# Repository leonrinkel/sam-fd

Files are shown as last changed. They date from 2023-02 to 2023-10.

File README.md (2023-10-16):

# sam-fd

ATSAMC21 based CAN-FD interface

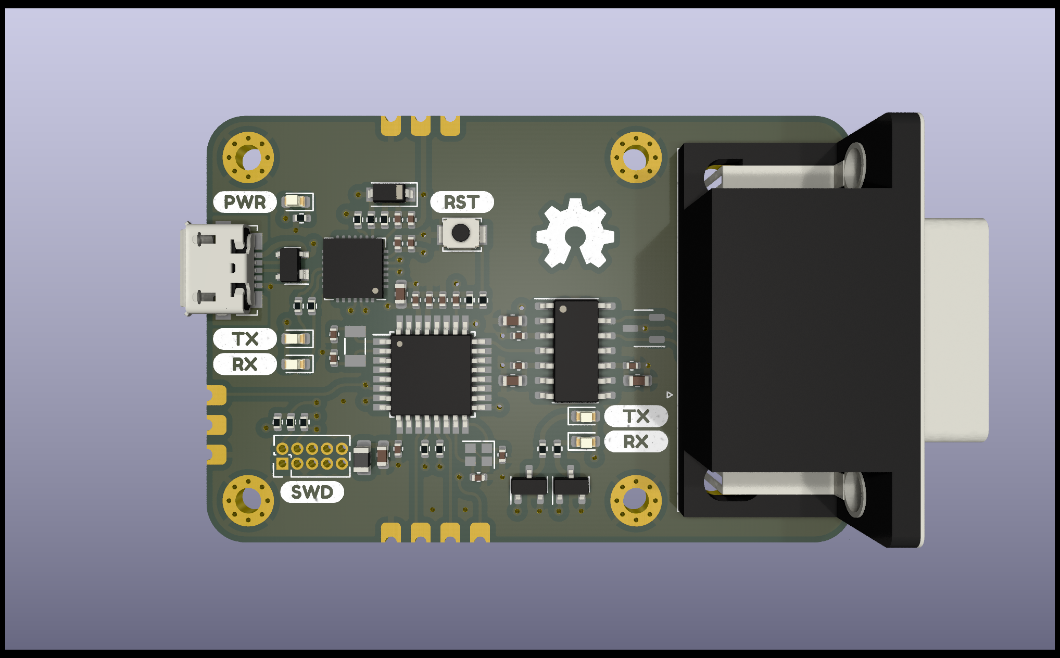
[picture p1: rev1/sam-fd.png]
Render of the interface PCB


## Initialization

Make sure you have a proper Zephyr development environment according to the official documentation.

```sh
west init -m https://git.leon.fyi/sam-fd-sdk --mr main sam-fd-workspace # or
west init -m https://github.com/leonrinkel/sam-fd-sdk --mr main sam-fd-workspace
cd sam-fd-workspace
west update
```

## Building

```sh
west build --sysbuild -b sam_fd sam-fd-sdk/app
```

## Flashing

### Using a Debugger

```sh
west flash --runner jlink # or
west flash --runner pyocd
```

### Via Serial Recovery

Serial recovery mode can be entered by running a command like the following immediately after resetting.

```sh
mcumgr \
    --conntype serial \
    --connstring dev=/dev/cu.usbserial-110,baud=115200 \
    image upload -e build/app/zephyr/zephyr.signed.bin
```

## License

Please see [hardware/LICENSE](rev1/LICENSE) and [sam-fd-sdk](https://git.leon.fyi/sam-fd-sdk). The software side of this project is based on [Zephyr](https://www.zephyrproject.org) which is mostly licensed under the [Apache-2.0](http://www.apache.org/licenses/LICENSE-2.0) license.

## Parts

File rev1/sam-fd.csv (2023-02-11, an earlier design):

Source: | /Users/leonrinkel/Documents/Git/leonrinkel/sam-fd/hardware/sam-fd.kicad_sch
Date: | 2023 February 11, Saturday 17:33:37
Tool: | Eeschema (6.0.10-0)
Generator: | /Applications/KiCad/KiCad.app/Contents/SharedSupport/plugins/bom_csv_grouped_by_value.py
Component Count: | 63
Individual Components:
Item | Qty | Reference(s) | Value | LibPart | Footprint | Datasheet | Mfr. | Mfr. No | Mouser No
 |  | C1 | 100pF | Device:C | Capacitor_SMD:C_0402_1005Metric | ./datasheets/GRM1555C1H101JA01_01A-1982687.pdf | Murata Electronics | GRM1555C1H101JA01D | 81-GRM1555C1H101JA1D
 |  | C2 | 4.7pF | Device:C | Capacitor_SMD:C_0402_1005Metric | ./datasheets/GJM1555C1H4R7WB01_01-1973175.pdf | Murata Electronics | GJM1555C1H4R7WB01D | 81-GJM1555C1H4R7WB1D
 |  | C3 | 4.7pF | Device:C | Capacitor_SMD:C_0402_1005Metric | ./datasheets/GJM1555C1H4R7WB01_01-1973175.pdf | Murata Electronics | GJM1555C1H4R7WB01D | 81-GJM1555C1H4R7WB1D
 |  | C4 | 10µF | Device:C | Capacitor_SMD:C_0603_1608Metric | ./datasheets/GRM188Z71A106KA73_01A-1986029.pdf | Murata Electronics | GRM188Z71A106KA73D | 81-GRM188Z71A106KA3D
 |  | C5 | 100nF | Device:C | Capacitor_SMD:C_0402_1005Metric | ./datasheets/GRM155R71A104KA01_01A-1983947.pdf | Murata Electronics | GRM155R71A104KA01D | 81-GRM155R71A104KA1D
 |  | C6 | 1µF | Device:C | Capacitor_SMD:C_0402_1005Metric | ./datasheets/GCM155C71A105KE38_01-1965360.pdf | Murata Electronics | GCM155C71A105KE38D | 81-GCM155C71A105KE8D
 |  | C7 | 10µF | Device:C | Capacitor_SMD:C_0603_1608Metric | ./datasheets/GRM188Z71A106KA73_01A-1986029.pdf | Murata Electronics | GRM188Z71A106KA73D | 81-GRM188Z71A106KA3D
 |  | C8 | 100nF | Device:C | Capacitor_SMD:C_0402_1005Metric | ./datasheets/GRM155R71A104KA01_01A-1983947.pdf | Murata Electronics | GRM155R71A104KA01D | 81-GRM155R71A104KA1D
 |  | C9 | 100nF | Device:C | Capacitor_SMD:C_0402_1005Metric | ./datasheets/GRM155R71A104KA01_01A-1983947.pdf | Murata Electronics | GRM155R71A104KA01D | 81-GRM155R71A104KA1D
 |  | C10 | 5.6pF | Device:C | Capacitor_SMD:C_0402_1005Metric | ./datasheets/GRM1555C1H5R6WA01_01A-1982816.pdf | Murata Electronics | GRM1555C1H5R6WA01D | 81-GRM1555C1H5R6WA1D
 |  | C11 | 5.6pF | Device:C | Capacitor_SMD:C_0402_1005Metric | ./datasheets/GRM1555C1H5R6WA01_01A-1982816.pdf | Murata Electronics | GRM1555C1H5R6WA01D | 81-GRM1555C1H5R6WA1D
 |  | C12 | 4.7µF | Device:C | Capacitor_SMD:C_0402_1005Metric | ./datasheets/GRM155R61A475MEAA_01A-1983870.pdf | Murata Electronics | GRM155R61A475MEAAD | 81-GRM155R61A475MEAD
 |  | C13 | 100nF | Device:C | Capacitor_SMD:C_0402_1005Metric | ./datasheets/GRM155R71A104KA01_01A-1983947.pdf | Murata Electronics | GRM155R71A104KA01D | 81-GRM155R71A104KA1D
 |  | C14 | 4.7µF | Device:C | Capacitor_SMD:C_0402_1005Metric | ./datasheets/GRM155R61A475MEAA_01A-1983870.pdf | Murata Electronics | GRM155R61A475MEAAD | 81-GRM155R61A475MEAD
 |  | C15 | 100nF | Device:C | Capacitor_SMD:C_0402_1005Metric | ./datasheets/GRM155R71A104KA01_01A-1983947.pdf | Murata Electronics | GRM155R71A104KA01D | 81-GRM155R71A104KA1D
 |  | C16 | 10µF | Device:C | Capacitor_SMD:C_0603_1608Metric | ./datasheets/GRM188Z71A106KA73_01A-1986029.pdf | Murata Electronics | GRM188Z71A106KA73D | 81-GRM188Z71A106KA3D
 |  | C17 | 100nF | Device:C | Capacitor_SMD:C_0402_1005Metric | ./datasheets/GRM155R71A104KA01_01A-1983947.pdf | Murata Electronics | GRM155R71A104KA01D | 81-GRM155R71A104KA1D
 |  | C18 | 10µF | Device:C | Capacitor_SMD:C_0603_1608Metric | ./datasheets/GRM188Z71A106KA73_01A-1986029.pdf | Murata Electronics | GRM188Z71A106KA73D | 81-GRM188Z71A106KA3D
 |  | C19 | 10µF | Device:C | Capacitor_SMD:C_0603_1608Metric | ./datasheets/GRM188Z71A106KA73_01A-1986029.pdf | Murata Electronics | GRM188Z71A106KA73D | 81-GRM188Z71A106KA3D
 |  | C20 | 100nF | Device:C | Capacitor_SMD:C_0402_1005Metric | ./datasheets/GRM155R71A104KA01_01A-1983947.pdf | Murata Electronics | GRM155R71A104KA01D | 81-GRM155R71A104KA1D
 |  | C21 | 100nF | Device:C | Capacitor_SMD:C_0402_1005Metric | ./datasheets/GRM155R71A104KA01_01A-1983947.pdf | Murata Electronics | GRM155R71A104KA01D | 81-GRM155R71A104KA1D
 |  | D1 | RED | Device:LED | LED_SMD:LED_0603_1608Metric | ./datasheets/LTST_C190KRKT-1141828.pdf | Lite-On | LTST-C190KRKT | 859-LTST-C190KRKT
 |  | D2 | GREEN | Device:LED | LED_SMD:LED_0603_1608Metric | ./datasheets/LTST_C190KGKT-1141861.pdf | Lite-On | LTST-C190KGKT | 859-LTST-C190KGKT
 |  | D3 | GREEN | Device:LED | LED_SMD:LED_0603_1608Metric | ./datasheets/LTST_C190KGKT-1141861.pdf | Lite-On | LTST-C190KGKT | 859-LTST-C190KGKT
 |  | D4 | SP0503BAHT | Power_Protection:SP0503BAHT | Package_TO_SOT_SMD:SOT-143 | ./datasheets/Littelfuse_TVS_Diode_Array_SP05_Datasheet_pdf-777043.pdf | Littelfuse | SP0503BAHTG | 576-SP0503BAHTG
 |  | D5 | MBR130T1G | Device:D_Schottky | Diode_SMD:D_SOD-123 | ./datasheets/MBR130T1_D-1810771.pdf | onsemi | MBR130T1G | 863-MBR130T1G
 |  | D6 | YELLOW | Device:LED | LED_SMD:LED_0603_1608Metric | ./datasheets/LTST_C190KSKT-1142011.pdf | Lite-On | LTST-C190KSKT | 859-LTST-C190KSKT
 |  | D7 | YELLOW | Device:LED | LED_SMD:LED_0603_1608Metric | ./datasheets/LTST_C190KSKT-1142011.pdf | Lite-On | LTST-C190KSKT | 859-LTST-C190KSKT
 |  | H1 | MountingHole_Pad | Mechanical:MountingHole_Pad | MountingHole:MountingHole_2.2mm_M2_Pad_Via | ~
 |  | H2 | MountingHole_Pad | Mechanical:MountingHole_Pad | MountingHole:MountingHole_2.2mm_M2_Pad_Via | ~
 |  | H3 | MountingHole_Pad | Mechanical:MountingHole_Pad | MountingHole:MountingHole_2.2mm_M2_Pad_Via | ~
 |  | H4 | MountingHole_Pad | Mechanical:MountingHole_Pad | MountingHole:MountingHole_2.2mm_M2_Pad_Via | ~
 |  | J1 | Conn_ARM_JTAG_SWD_10 | Connector:Conn_ARM_JTAG_SWD_10 | sam-fd:PinHeader_2x05_P1.27mm_Vertical | http://infocenter.arm.com/help/topic/com.arm.doc.ddi0314h/DDI0314H_coresight_components_trm.pdf
 |  | J2 | USB_B_Micro | Connector:USB_B_Micro | sam-fd:USB_Micro-B_Molex_47346-0001 | ./datasheets/0473460001_IO_CONNECTORS-229243.pdf | Molex | 47346-0001 | 538-47346-0001
 |  | J3 | DB9_Male_MountingHoles | Connector:DB9_Male_MountingHoles | Connector_Dsub:DSUB-9_Male_Horizontal_P2.77x2.84mm_EdgePinOffset9.90mm_Housed_MountingHolesOffset11.32mm | ./datasheets/io_dsub_brochure.pdf | Amphenol FCI | D09P33E6RV09LF | 649-D09P33E6RV09LF
 |  | J4 | Conn_01x04 | Connector_Generic:Conn_01x04 | sam-fd:CastellatedHoles_1x04_P2.54mm | ~
 |  | J5 | Conn_01x03 | Connector_Generic:Conn_01x03 | sam-fd:CastellatedHoles_1x03_P2.54mm | ~
 |  | J6 | Conn_01x03 | Connector_Generic:Conn_01x03 | sam-fd:CastellatedHoles_1x03_P2.54mm | ~
 |  | L1 | 39nH | Device:L | Inductor_SMD:L_0805_2012Metric | ./datasheets/ce201210-777343.pdf | Bourns | CE201210-39NJ | 652-CE201210-39NJ
 |  | Q1 | Q_NPN_BEC | Device:Q_NPN_BEC | Package_TO_SOT_SMD:SOT-23 | ./datasheets/MMSS8050_SOT_23_-1626440.pdf | Micro Commercial Components (MCC) | MMSS8050-L-TP | 833-MMSS8050-L-TP
 |  | Q2 | Q_NPN_BEC | Device:Q_NPN_BEC | Package_TO_SOT_SMD:SOT-23 | ./datasheets/MMSS8050_SOT_23_-1626440.pdf | Micro Commercial Components (MCC) | MMSS8050-L-TP | 833-MMSS8050-L-TP
 |  | R1 | 68Ω | Device:R | Resistor_SMD:R_0402_1005Metric | ./datasheets/PYu_RC_Group_51_RoHS_L_11-1984063.pdf | YAGEO | RC0402FR-0768RL | 603-RC0402FR-0768RL
 |  | R2 | 68Ω | Device:R | Resistor_SMD:R_0402_1005Metric | ./datasheets/PYu_RC_Group_51_RoHS_L_11-1984063.pdf | YAGEO | RC0402FR-0768RL | 603-RC0402FR-0768RL
 |  | R3 | 68Ω | Device:R | Resistor_SMD:R_0402_1005Metric | ./datasheets/PYu_RC_Group_51_RoHS_L_11-1984063.pdf | YAGEO | RC0402FR-0768RL | 603-RC0402FR-0768RL
 |  | R4 | 2.2kΩ | Device:R | Resistor_SMD:R_0402_1005Metric | ./datasheets/PYu_RC_Group_51_RoHS_L_11-1984063.pdf | YAGEO | RC0402FR-072K2L | 603-RC0402FR-072K2L
 |  | R5 | 330Ω | Device:R | Resistor_SMD:R_0402_1005Metric | ./datasheets/crcwce3-1762584.pdf | Vishay / Dale | CRCW0402330RJNEDC | 71-CRCW0402330RJNEDC
 |  | R6 | 10kΩ | Device:R | Resistor_SMD:R_0402_1005Metric | ./datasheets/PYu_RC_Group_51_RoHS_L_11-1984063.pdf | YAGEO | RC0402FR-0710KL | 603-RC0402FR-0710KL
 |  | R7 | 10kΩ | Device:R | Resistor_SMD:R_0402_1005Metric | ./datasheets/PYu_RC_Group_51_RoHS_L_11-1984063.pdf | YAGEO | RC0402FR-0710KL | 603-RC0402FR-0710KL
 |  | R8 | 22Ω | Device:R | Resistor_SMD:R_0402_1005Metric | ./datasheets/PYu_RC_Group_51_RoHS_L_11-1984063.pdf | YAGEO | RC0402FR-0722RL | 603-RC0402FR-0722RL
 |  | R9 | 22.1kΩ | Device:R | Resistor_SMD:R_0402_1005Metric | ./datasheets/crcwce3-1762584.pdf | Vishay / Dale | CRCW040222K1FKEDC | 71-CRCW040222K1FKEDC
 |  | R10 | 47.5kΩ | Device:R | Resistor_SMD:R_0402_1005Metric | ./datasheets/crcwce3-1762584.pdf | Vishay / Dale | CRCW040247K5FKEDC | 71-CRCW040247K5FKEDC
 |  | R11 | 1kΩ | Device:R | Resistor_SMD:R_0402_1005Metric | ./datasheets/crcwce3-1762584.pdf | Vishay / Dale | CRCW04021K00JNEDC | 71-CRCW04021K00JNEDC
 |  | R12 | 68Ω | Device:R | Resistor_SMD:R_0402_1005Metric | ./datasheets/PYu_RC_Group_51_RoHS_L_11-1984063.pdf | YAGEO | RC0402FR-0768RL | 603-RC0402FR-0768RL
 |  | R13 | 68Ω | Device:R | Resistor_SMD:R_0402_1005Metric | ./datasheets/PYu_RC_Group_51_RoHS_L_11-1984063.pdf | YAGEO | RC0402FR-0768RL | 603-RC0402FR-0768RL
 |  | R14 | 47.5kΩ | Device:R | Resistor_SMD:R_0402_1005Metric | ./datasheets/crcwce3-1762584.pdf | Vishay / Dale | CRCW040247K5FKEDC | 71-CRCW040247K5FKEDC
 |  | R15 | 47.5kΩ | Device:R | Resistor_SMD:R_0402_1005Metric | ./datasheets/crcwce3-1762584.pdf | Vishay / Dale | CRCW040247K5FKEDC | 71-CRCW040247K5FKEDC
 |  | SW1 | SW_Push | Switch:SW_Push | Button_Switch_SMD:SW_SPST_B3U-1000P | ./datasheets/en-b3u-3615.pdf | Omron Electronics | B3U-1000P | 653-B3U-1000P
 |  | U1 | ATSAMC21E | sam-fd:ATSAMC21E | Package_QFP:TQFP-32_7x7mm_P0.8mm | ./datasheets/SAM_C20_C21_Family_Data_Sheet_DS60001479J-2902525.pdf | Microchip Technology / Atmel | ATSAMC21E16A-ANT | 556-ATSAMC21E16A-ANT
 |  | U2 | CP2102N-Axx-xQFN28 | Interface_USB:CP2102N-Axx-xQFN28 | Package_DFN_QFN:QFN-28-1EP_5x5mm_P0.5mm_EP3.35x3.35mm | ./datasheets/cp2102n_datasheet-1634912.pdf | Silicon Labs | CP2102N-A02-GQFN28 | 634-CP2102NA02GQFN28
 |  | U3 | TJA1443AT | sam-fd:TJA1443AT | Package_SO:SO-14_3.9x8.65mm_P1.27mm | ./datasheets/TJA1443-1949290.pdf | NXP Semiconductors | TJA1443AT/0Z | 771-TJA1443AT/0Z
 |  | U4 | PESD2CANFD24L | sam-fd:PESD2CANFD24L | Package_TO_SOT_SMD:SOT-23-3 | ./datasheets/PESD2CANFD24L_T-1892242.pdf | Nexperia | PESD2CANFD24L-TR | 771-PESD2CANFD24L-TR
 |  | Y1 | 32.768kHz | Device:Crystal | Crystal:Crystal_SMD_3215-2Pin_3.2x1.5mm | ./datasheets/ABS07-3080027.pdf | ABRACON | ABS07-32.768KHZ-7-T | 815-ABS07-32.768K7T
 |  | Y2 | 32MHz | Device:Crystal_GND24 | Crystal:Crystal_SMD_2016-4Pin_2.0x1.6mm | ./datasheets/ABM11W-1774757.pdf | ABRACON | ABM11W-32.0000MHZ-8-D1X-T3 | 815-11W32-8D1XT
Collated Components:
Item | Qty | Reference(s) | Value | LibPart | Footprint | Datasheet | Mfr. | Mfr. No | Mouser No
1 | 1 | C1 | 100pF | Device:C | Capacitor_SMD:C_0402_1005Metric | ./datasheets/GRM1555C1H101JA01_01A-1982687.pdf | Murata Electronics | GRM1555C1H101JA01D | 81-GRM1555C1H101JA1D
2 | 2 | C2, C3 | 4.7pF | Device:C | Capacitor_SMD:C_0402_1005Metric | ./datasheets/GJM1555C1H4R7WB01_01-1973175.pdf | Murata Electronics | GJM1555C1H4R7WB01D | 81-GJM1555C1H4R7WB1D
3 | 5 | C4, C7, C16, C18, C19 | 10µF | Device:C | Capacitor_SMD:C_0603_1608Metric | ./datasheets/GRM188Z71A106KA73_01A-1986029.pdf | Murata Electronics | GRM188Z71A106KA73D | 81-GRM188Z71A106KA3D
4 | 8 | C5, C8, C9, C13, C15, C17, C20, C21 | 100nF | Device:C | Capacitor_SMD:C_0402_1005Metric | ./datasheets/GRM155R71A104KA01_01A-1983947.pdf | Murata Electronics | GRM155R71A104KA01D | 81-GRM155R71A104KA1D
5 | 1 | C6 | 1µF | Device:C | Capacitor_SMD:C_0402_1005Metric | ./datasheets/GCM155C71A105KE38_01-1965360.pdf | Murata Electronics | GCM155C71A105KE38D | 81-GCM155C71A105KE8D
6 | 2 | C10, C11 | 5.6pF | Device:C | Capacitor_SMD:C_0402_1005Metric | ./datasheets/GRM1555C1H5R6WA01_01A-1982816.pdf | Murata Electronics | GRM1555C1H5R6WA01D | 81-GRM1555C1H5R6WA1D
7 | 2 | C12, C14 | 4.7µF | Device:C | Capacitor_SMD:C_0402_1005Metric | ./datasheets/GRM155R61A475MEAA_01A-1983870.pdf | Murata Electronics | GRM155R61A475MEAAD | 81-GRM155R61A475MEAD
8 | 1 | D1 | RED | Device:LED | LED_SMD:LED_0603_1608Metric | ./datasheets/LTST_C190KRKT-1141828.pdf | Lite-On | LTST-C190KRKT | 859-LTST-C190KRKT
9 | 2 | D2, D3 | GREEN | Device:LED | LED_SMD:LED_0603_1608Metric | ./datasheets/LTST_C190KGKT-1141861.pdf | Lite-On | LTST-C190KGKT | 859-LTST-C190KGKT
10 | 1 | D4 | SP0503BAHT | Power_Protection:SP0503BAHT | Package_TO_SOT_SMD:SOT-143 | ./datasheets/Littelfuse_TVS_Diode_Array_SP05_Datasheet_pdf-777043.pdf | Littelfuse | SP0503BAHTG | 576-SP0503BAHTG
11 | 1 | D5 | MBR130T1G | Device:D_Schottky | Diode_SMD:D_SOD-123 | ./datasheets/MBR130T1_D-1810771.pdf | onsemi | MBR130T1G | 863-MBR130T1G
12 | 2 | D6, D7 | YELLOW | Device:LED | LED_SMD:LED_0603_1608Metric | ./datasheets/LTST_C190KSKT-1142011.pdf | Lite-On | LTST-C190KSKT | 859-LTST-C190KSKT
13 | 4 | H1, H2, H3, H4 | MountingHole_Pad | Mechanical:MountingHole_Pad | MountingHole:MountingHole_2.2mm_M2_Pad_Via | ~
14 | 1 | J1 | Conn_ARM_JTAG_SWD_10 | Connector:Conn_ARM_JTAG_SWD_10 | sam-fd:PinHeader_2x05_P1.27mm_Vertical | http://infocenter.arm.com/help/topic/com.arm.doc.ddi0314h/DDI0314H_coresight_components_trm.pdf
15 | 1 | J2 | USB_B_Micro | Connector:USB_B_Micro | sam-fd:USB_Micro-B_Molex_47346-0001 | ./datasheets/0473460001_IO_CONNECTORS-229243.pdf | Molex | 47346-0001 | 538-47346-0001
16 | 1 | J3 | DB9_Male_MountingHoles | Connector:DB9_Male_MountingHoles | Connector_Dsub:DSUB-9_Male_Horizontal_P2.77x2.84mm_EdgePinOffset9.90mm_Housed_MountingHolesOffset11.32mm | ./datasheets/io_dsub_brochure.pdf | Amphenol FCI | D09P33E6RV09LF | 649-D09P33E6RV09LF
17 | 1 | J4 | Conn_01x04 | Connector_Generic:Conn_01x04 | sam-fd:CastellatedHoles_1x04_P2.54mm | ~
18 | 2 | J5, J6 | Conn_01x03 | Connector_Generic:Conn_01x03 | sam-fd:CastellatedHoles_1x03_P2.54mm | ~
19 | 1 | L1 | 39nH | Device:L | Inductor_SMD:L_0805_2012Metric | ./datasheets/ce201210-777343.pdf | Bourns | CE201210-39NJ | 652-CE201210-39NJ
20 | 2 | Q1, Q2 | Q_NPN_BEC | Device:Q_NPN_BEC | Package_TO_SOT_SMD:SOT-23 | ./datasheets/MMSS8050_SOT_23_-1626440.pdf | Micro Commercial Components (MCC) | MMSS8050-L-TP | 833-MMSS8050-L-TP
21 | 5 | R1, R2, R3, R12, R13 | 68Ω | Device:R | Resistor_SMD:R_0402_1005Metric | ./datasheets/PYu_RC_Group_51_RoHS_L_11-1984063.pdf | YAGEO | RC0402FR-0768RL | 603-RC0402FR-0768RL
22 | 1 | R4 | 2.2kΩ | Device:R | Resistor_SMD:R_0402_1005Metric | ./datasheets/PYu_RC_Group_51_RoHS_L_11-1984063.pdf | YAGEO | RC0402FR-072K2L | 603-RC0402FR-072K2L
23 | 1 | R5 | 330Ω | Device:R | Resistor_SMD:R_0402_1005Metric | ./datasheets/crcwce3-1762584.pdf | Vishay / Dale | CRCW0402330RJNEDC | 71-CRCW0402330RJNEDC
24 | 2 | R6, R7 | 10kΩ | Device:R | Resistor_SMD:R_0402_1005Metric | ./datasheets/PYu_RC_Group_51_RoHS_L_11-1984063.pdf | YAGEO | RC0402FR-0710KL | 603-RC0402FR-0710KL
25 | 1 | R8 | 22Ω | Device:R | Resistor_SMD:R_0402_1005Metric | ./datasheets/PYu_RC_Group_51_RoHS_L_11-1984063.pdf | YAGEO | RC0402FR-0722RL | 603-RC0402FR-0722RL
26 | 1 | R9 | 22.1kΩ | Device:R | Resistor_SMD:R_0402_1005Metric | ./datasheets/crcwce3-1762584.pdf | Vishay / Dale | CRCW040222K1FKEDC | 71-CRCW040222K1FKEDC
27 | 3 | R10, R14, R15 | 47.5kΩ | Device:R | Resistor_SMD:R_0402_1005Metric | ./datasheets/crcwce3-1762584.pdf | Vishay / Dale | CRCW040247K5FKEDC | 71-CRCW040247K5FKEDC
28 | 1 | R11 | 1kΩ | Device:R | Resistor_SMD:R_0402_1005Metric | ./datasheets/crcwce3-1762584.pdf | Vishay / Dale | CRCW04021K00JNEDC | 71-CRCW04021K00JNEDC
29 | 1 | SW1 | SW_Push | Switch:SW_Push | Button_Switch_SMD:SW_SPST_B3U-1000P | ./datasheets/en-b3u-3615.pdf | Omron Electronics | B3U-1000P | 653-B3U-1000P
30 | 1 | U1 | ATSAMC21E | sam-fd:ATSAMC21E | Package_QFP:TQFP-32_7x7mm_P0.8mm | ./datasheets/SAM_C20_C21_Family_Data_Sheet_DS60001479J-2902525.pdf | Microchip Technology / Atmel | ATSAMC21E16A-ANT | 556-ATSAMC21E16A-ANT
31 | 1 | U2 | CP2102N-Axx-xQFN28 | Interface_USB:CP2102N-Axx-xQFN28 | Package_DFN_QFN:QFN-28-1EP_5x5mm_P0.5mm_EP3.35x3.35mm | ./datasheets/cp2102n_datasheet-1634912.pdf | Silicon Labs | CP2102N-A02-GQFN28 | 634-CP2102NA02GQFN28
32 | 1 | U3 | TJA1443AT | sam-fd:TJA1443AT | Package_SO:SO-14_3.9x8.65mm_P1.27mm | ./datasheets/TJA1443-1949290.pdf | NXP Semiconductors | TJA1443AT/0Z | 771-TJA1443AT/0Z
33 | 1 | U4 | PESD2CANFD24L | sam-fd:PESD2CANFD24L | Package_TO_SOT_SMD:SOT-23-3 | ./datasheets/PESD2CANFD24L_T-1892242.pdf | Nexperia | PESD2CANFD24L-TR | 771-PESD2CANFD24L-TR
34 | 1 | Y1 | 32.768kHz | Device:Crystal | Crystal:Crystal_SMD_3215-2Pin_3.2x1.5mm | ./datasheets/ABS07-3080027.pdf | ABRACON | ABS07-32.768KHZ-7-T | 815-ABS07-32.768K7T
35 | 1 | Y2 | 32MHz | Device:Crystal_GND24 | Crystal:Crystal_SMD_2016-4Pin_2.0x1.6mm | ./datasheets/ABM11W-1774757.pdf | ABRACON | ABM11W-32.0000MHZ-8-D1X-T3 | 815-11W32-8D1XT

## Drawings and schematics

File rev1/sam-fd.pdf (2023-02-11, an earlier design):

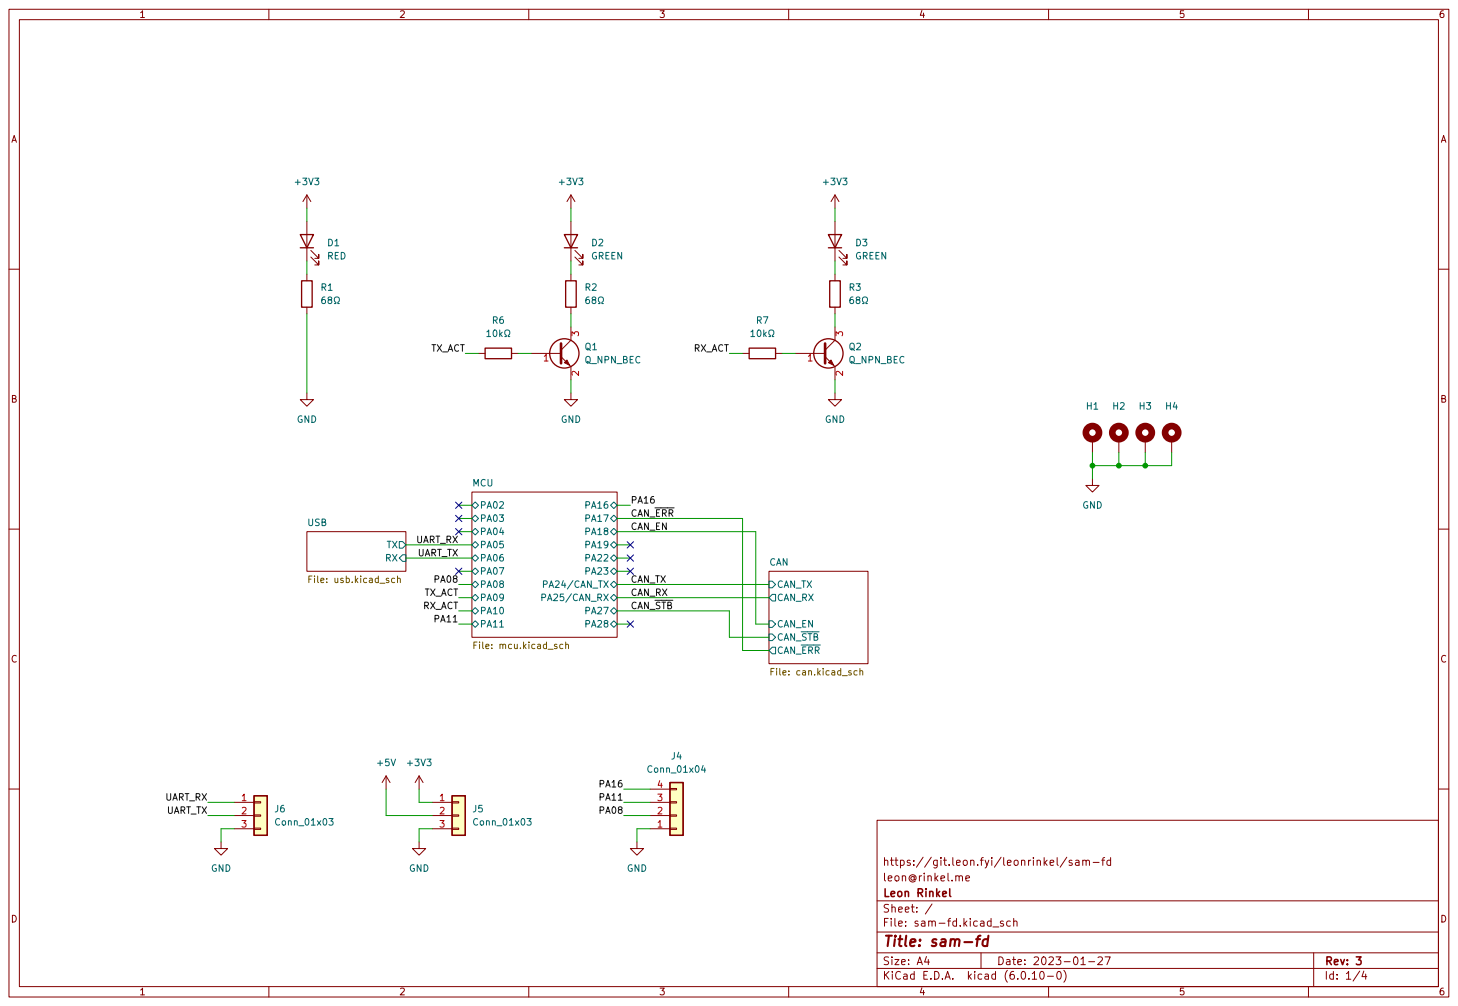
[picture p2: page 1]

https://git.leon.fyi/leonrinkel/sam-fd PA17 PA18 PA19 PA16 PA22 PA23 PA24/CAN_TX

leon@rinkel.me
File: sam-fd.kicad_sch Sheet: / Leon Rinkel

Id: 1/4 Title: sam-fd

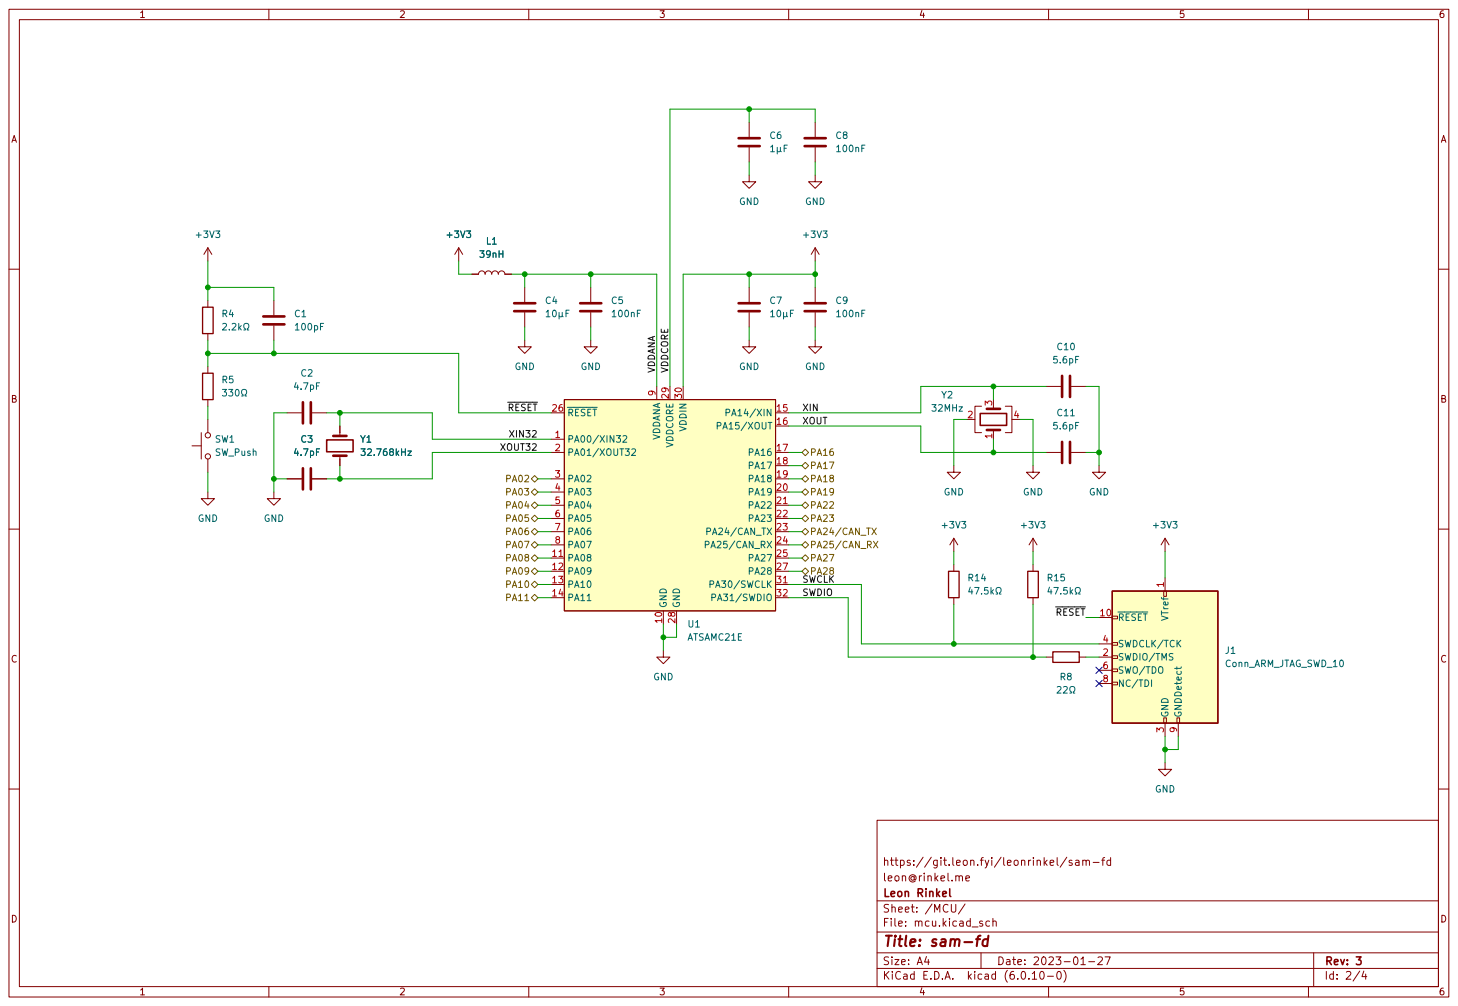
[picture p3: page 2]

3 SWDCLK/TCK 4 SWO/TDO 6 NC/TDI 8 GNDDetect 9

https://git.leon.fyi/leonrinkel/sam-fd
leon@rinkel.me
File: mcu.kicad_sch Sheet: /MCU/ Leon Rinkel

Id: 2/4 Title: sam-fd

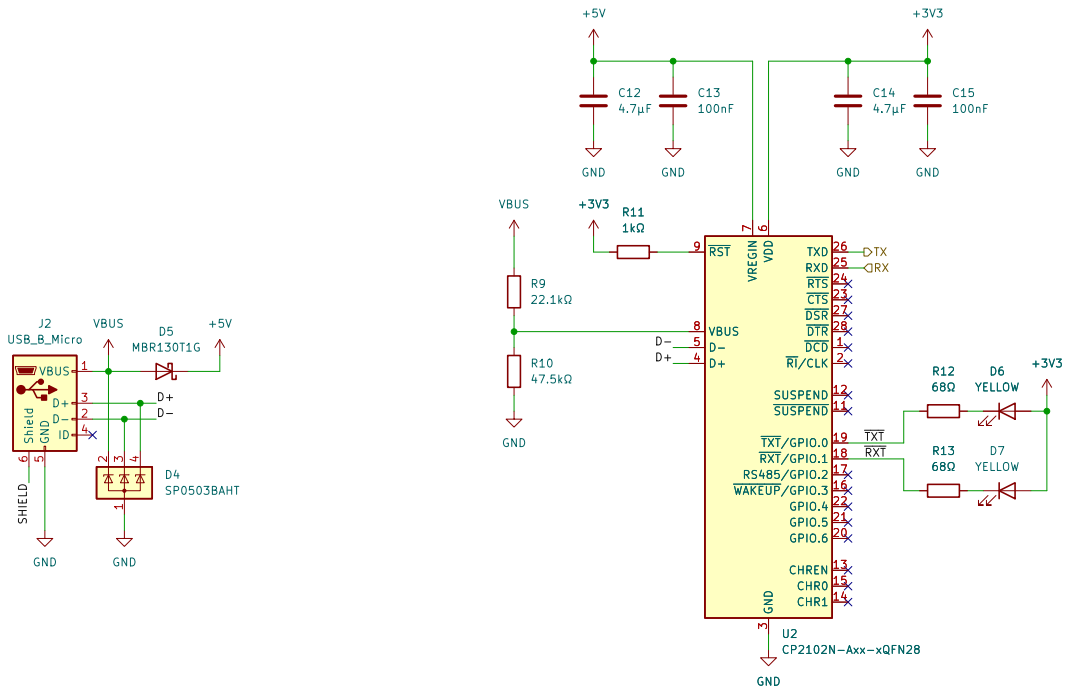
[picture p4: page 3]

https://git.leon.fyi/leonrinkel/sam-fd
leon@rinkel.me
File: usb.kicad_sch Sheet: /USB/ Leon Rinkel

Id: 3/4 Title: sam-fd

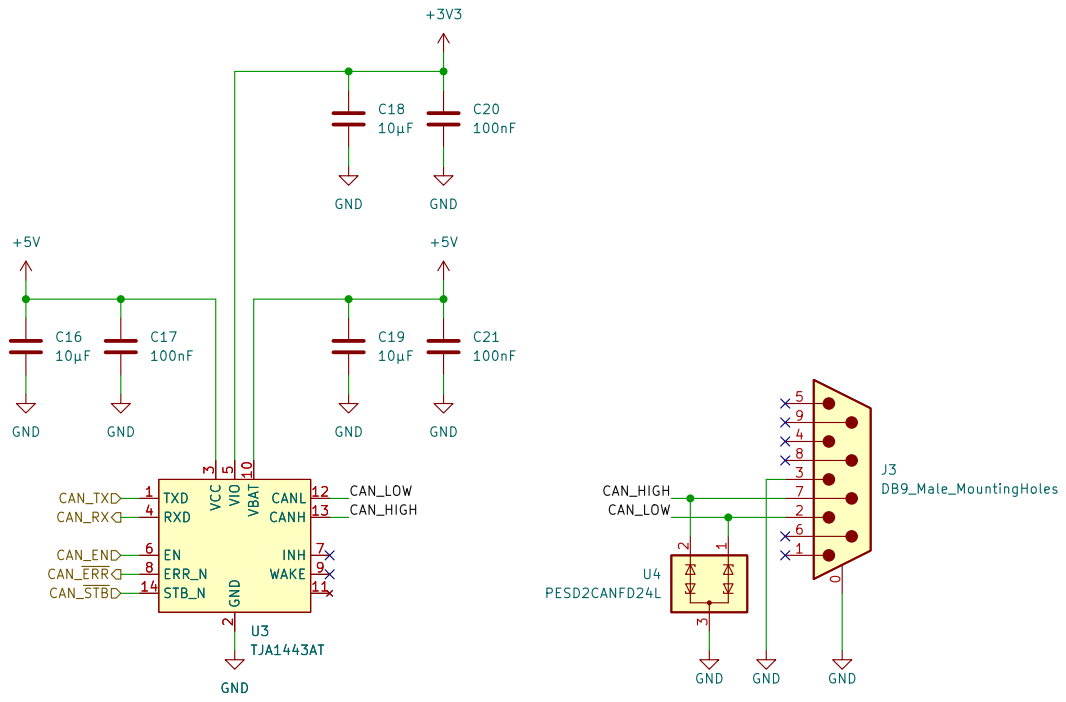
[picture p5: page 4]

1 U4 PESD2CANFD24L GND GND GND GND

https://git.leon.fyi/leonrinkel/sam-fd C16

leon@rinkel.me
File: can.kicad_sch Sheet: /CAN/ Leon Rinkel

Id: 4/4 Title: sam-fd

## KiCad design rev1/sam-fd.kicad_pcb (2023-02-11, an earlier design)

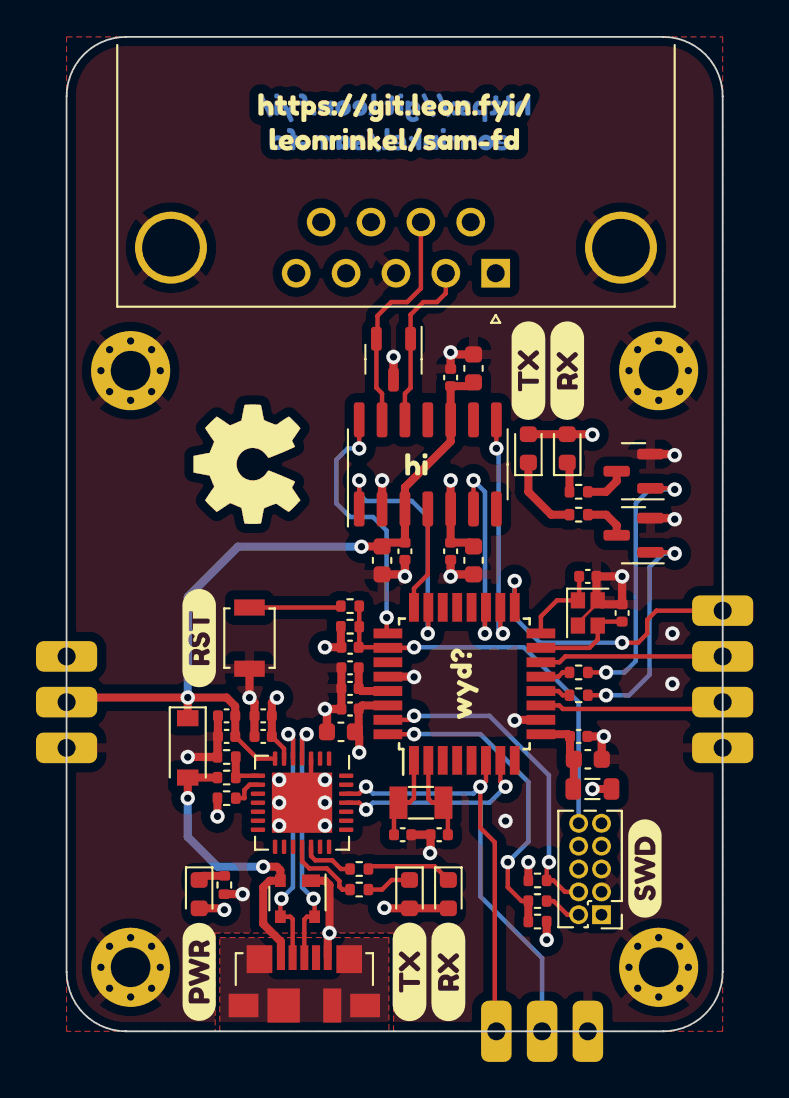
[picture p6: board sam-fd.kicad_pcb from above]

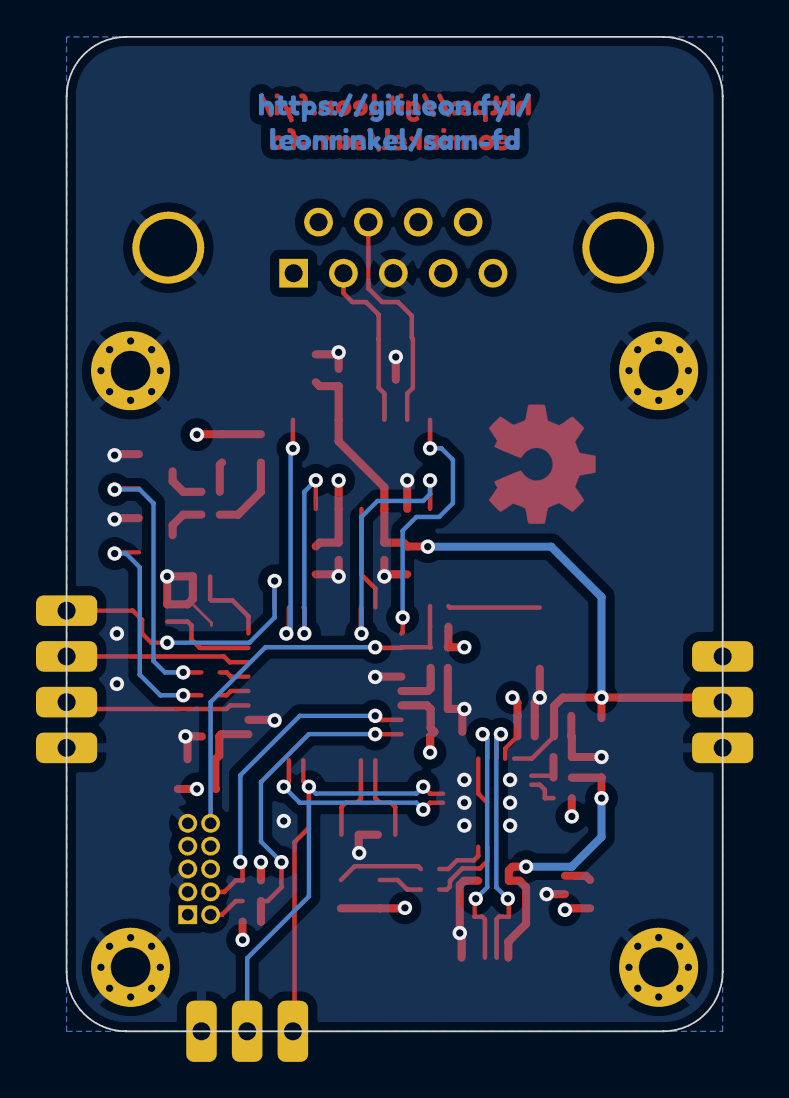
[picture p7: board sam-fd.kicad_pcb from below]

Board: 4 copper layers, 36.4 x 55.2 mm, 78 parts (2 on the bottom side), 44 nets.

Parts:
C1: 100pF; C_0402_1005Metric
C2, C3: 4.7pF; C_0402_1005Metric
C4, C7, C16, C18, C19: 10µF; C_0603_1608Metric
C5, C8, C9, C13, C15, C17, C20, C21: 100nF; C_0402_1005Metric
C6: 1µF; C_0402_1005Metric
C10, C11: 5.6pF; C_0402_1005Metric
C12, C14: 4.7µF; C_0402_1005Metric
D1: RED; LED_0603_1608Metric
D2, D3: GREEN; LED_0603_1608Metric
D4: SP0503BAHT; SOT-143
D5: MBR130T1G; D_SOD-123
D6, D7: YELLOW; LED_0603_1608Metric
H1, H2, H3, H4: MountingHole_Pad; MountingHole_2.2mm_M2_Pad_Via
J1: Conn_ARM_JTAG_SWD_10; PinHeader_2x05_P1.27mm_Vertical
J2: USB_B_Micro; USB_Micro-B_Molex_47346-0001
J3: DB9_Male_MountingHoles; DSUB-9_Male_Horizontal_P2.77x2.84mm_EdgePinOffset9.90mm_Hou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
J4: Conn_01x04; CastellatedHoles_1x04_P2.54mm
J5, J6: Conn_01x03; CastellatedHoles_1x03_P2.54mm
L1: 39nH; L_0805_2012Metric
Q1, Q2: Q_NPN_BEC; SOT-23
R1, R2, R3, R12, R13: 68Ω; R_0402_1005Metric
R4: 2.2kΩ; R_0402_1005Metric
R5: 330Ω; R_0402_1005Metric
R6, R7: 10kΩ; R_0402_1005Metric
R8: 22Ω; R_0402_1005Metric
R9: 22.1kΩ; R_0402_1005Metric
R10, R14, R15: 47.5kΩ; R_0402_1005Metric
R11: 1kΩ; R_0402_1005Metric
SW1: SW_Push; SW_SPST_B3U-1000P
U1: ATSAMC21E; TQFP-32_7x7mm_P0.8mm
U2: CP2102N-Axx-xQFN28; QFN-28-1EP_5x5mm_P0.5mm_EP3.35x3.35mm
U3: TJA1443AT; SO-14_3.9x8.65mm_P1.27mm
U4: PESD2CANFD24L; SOT-23-3
Y1: 32.768kHz; Crystal_SMD_3215-2Pin_3.2x1.5mm
Y2: 32MHz; Crystal_SMD_2016-4Pin_2.0x1.6mm
kibuzzard-63D3DC5C, kibuzzard-63D3DC5C#2: G***; kibuzzard-63D3DC5C
kibuzzard-63D3DC15: G***; kibuzzard-63D3DC15
kibuzzard-63D3DC51, kibuzzard-63D3DC51#2: G***; kibuzzard-63D3DC51
kibuzzard-63D40F1D: G***; kibuzzard-63D40F1D
kibuzzard-63D41F74: G***; kibuzzard-63D41F74
kibuzzard-63D420B8: G***; kibuzzard-63D420B8
kibuzzard-63D40257: G***; kibuzzard-63D40257
kibuzzard-63E7A1A7: G***; kibuzzard-63E7A1A7
kibuzzard-63E7A1EC: G***; kibuzzard-63E7A1EC
kibuzzard-63E7A1F6: G***; kibuzzard-63E7A1F6
kibuzzard-63E7A25C: G***; kibuzzard-63E7A25C
kibuzzard-63E7A195: G***; kibuzzard-63E7A195
kibuzzard-63E7A280: G***; kibuzzard-63E7A280

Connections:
+3V3: C1.1, C7.1, C9.1, C14.1, C15.1, C18.1, C20.1, D1.2 (A), D2.2 (A), D3.2 (A), D6.2 (A), D7.2 (A), J1.1 (VTref), J5.1, L1.1, R4.1, R11.1, R14.1, R15.1, U1.30 (VDDIN), U2.6 (VDD), U3.5 (VIO)
+5V: C12.1, C13.1, C16.1, C17.1, C19.1, C21.1, D5.1 (K), J5.2, U2.7 (VREGIN), U3.3 (VCC), U3.10 (VBAT)
/CAN/CAN_HIGH: J3.7, U3.13 (CANH), U4.2
/CAN/CAN_LOW: J3.2, U3.12 (CANL), U4.1
/CAN_EN: U1.19 (PA18), U3.6 (EN)
/CAN_RX: U1.24 (PA25/CAN_RX), U3.4 (RXD)
/CAN_TX: U1.23 (PA24/CAN_TX), U3.1 (TXD)
/CAN_~ERR: U1.18 (PA17), U3.8 (ERR_N)
/CAN_~STB: U1.25 (PA27), U3.14 (STB_N)
/MCU/SWCLK: J1.4 (SWDCLK/TCK), R14.2, U1.31 (PA30/SWCLK)
/MCU/SWDIO: R8.1, R15.2, U1.32 (PA31/SWDIO)
/MCU/VDDANA: C4.1, C5.1, L1.2, U1.9 (VDDANA)
/MCU/VDDCORE: C6.1, C8.1, U1.29 (VDDCORE)
/MCU/XIN: C10.1, U1.15 (PA14/XIN), Y2.3
/MCU/XIN32: C2.2, U1.1 (PA00/XIN32), Y1.2
/MCU/XOUT: C11.1, U1.16 (PA15/XOUT), Y2.1
/MCU/XOUT32: C3.2, U1.2 (PA01/XOUT32), Y1.1
/MCU/~RESET: C1.2, J1.10 (~RESET), R4.2, R5.1, U1.26 (~RESET)
/PA08: J4.2, U1.11 (PA08)
/PA11: J4.3, U1.14 (PA11)
/PA16: J4.4, U1.17 (PA16)
/RX_ACT: R7.1, U1.13 (PA10)
/TX_ACT: R6.1, U1.12 (PA09)
/UART_RX: J6.1, U1.6 (PA05), U2.26 (TXD)
/UART_TX: J6.2, U1.7 (PA06), U2.25 (RXD)
/USB/D+: D4.4 (K), J2.3 (D+), U2.4 (D+)
/USB/D-: D4.3 (K), J2.2 (D-), U2.5 (D-)
/USB/~RXT: R13.1, U2.18 (~RXT/GPIO.1)
/USB/~TXT: R12.1, U2.19 (~TXT/GPIO.0)
GND: C2.1, C3.1, C4.2, C5.2, C6.2, C7.2, C8.2, C9.2, C10.2, C11.2, C12.2, C13.2, C14.2, C15.2, C16.2, C17.2, C18.2, C19.2, C20.2, C21.2, D4.1 (A), H1.1, H2.1, H3.1, H4.1, J1.3 (GND), J1.5 (GND), J1.9 (GNDDetect), J2.5 (GND), J3.0 (PAD), J3.3, J4.1, J5.3, J6.3, Q1.2 (E), Q2.2 (E), R1.2, R10.2, SW1.1, U1.10 (GND), U1.28 (GND), U2.3 (GND), U2.29 (GND), U3.2 (GND), U4.3, Y2.2, Y2.4
unnamed: D1.1 (K), R1.1
unnamed: D2.1 (K), R2.1
unnamed: D3.1 (K), R3.1
unnamed: D6.1 (K), R12.2
unnamed: D7.1 (K), R13.2
unnamed: J1.2 (SWDIO/TMS), R8.2
unnamed: Q1.1 (B), R6.2
unnamed: Q1.3 (C), R2.2
unnamed: Q2.1 (B), R7.2
unnamed: Q2.3 (C), R3.2
unnamed: R5.2, SW1.2
unnamed: R9.2, R10.1, U2.8 (VBUS)
unnamed: R11.2, U2.9 (~RST)
VBUS: D4.2 (K), D5.2 (A), J2.1 (VBUS), R9.1

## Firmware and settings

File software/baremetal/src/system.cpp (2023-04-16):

/**
 * \file src/system.cpp
 * \author Rinkel, Leon <leon@rinkel.me>
 *
 * Implementation of low-level processor stuff such as the vector table.
 */

#include "system.hpp"

#include "samfd.hpp"
#include "types.hpp"
#include "linked.hpp"

/**
 * Main function.
 *
 * We could just call our wrapper class in the reset handler but some debuggers
 * seem to require a main function to work properly.
 */
int main(void)
{
	samfd().run();
	return 0;
}

/**
 * Handles the reset exception.
 *
 * Reset is invoked on power up or a warm reset. The exception model treats
 * reset as a special form of exception. When reset is asserted, the
 * operation of the processor stops, potentially at any point in an
 * instruction. When reset is deasserted, execution restarts from the
 * address provided by the reset entry in the vector table. Execution
 * restarts as privileged execution in Thread mode.
 */
void reset_handler(void)
{
	uint32_t* src;
	uint32_t* dst;
	uint32_t  cnt;
	uint32_t  idx;

	/* Relocate data section. */
	src = &_sdata;
	dst = &_sdata_reloc;
	while (dst < &_edata_reloc)
	{
		*dst++ = *src++;
	}

	/* Clear bss section. */
	dst = &_sbss;
	while (dst < &_ebss)
	{
		*dst++ = 0;
	}

	/* Call constructors. */
	cnt = _einit_array - _sinit_array;
	for (idx = 0; idx < cnt; idx++)
	{
		((void(*)(void)) _sinit_array[idx])();
	}

	/* Call main entry point. */
	main();

	/* Call destructors. */
	cnt = _efini_array - _sfini_array;
	for (idx = 0; idx < cnt; idx++)
	{
		((void(*)(void)) _sfini_array[idx])();
	}

	/* Infinite loop. */
	while (true)
	{
		__asm__("nop");
	}
}

/** NMI handler.
 *
 * A Non-Maskable Interrupt (NMI) can be signalled by a peripheral or
 * triggered by software. This is the highest priority exception other than
 * reset. It is permanently enabled and has a fixed priority of –2. NMIs
 * cannot be:
 * - Masked or prevented from activation by any other exception.
 * - Preempted by any exception other than Reset.
 */
void __attribute__((interrupt)) nmi_handler(void) {}

/**
 * HardFault handler.
 *
 * A HardFault is an exception that occurs because of an error. HardFaults
 * have a fixed priority of –1, meaning they have higher priority than any
 * exception with configurable priority.
 */
void __attribute__((interrupt)) hard_fault_handler(void)
{
	/* Infinite loop so that we can see we hard faulted. */
	while (true)
	{
		__asm__("nop");
	}
}

/**
 * SV call handler.
 *
 * A Supervisor Call (SVC) is an exception that is triggered by the SVC
 * instruction. In an OS environment, applications can use SVC instructions
 * to access OS kernel functions and device drivers.
 */
void __attribute__((interrupt)) sv_call_handler(void) {}

/**
 * PendSV handler.
 *
 * PendSV is an interrupt-driven request for system-level service. In an OS
 * environment, use PendSV for context switching when no other exception is
 * active.
 */
void __attribute__((interrupt)) pend_sv_handler(void) {}

/**
 * SysTick handler.
 *
 * If the device implements the SysTick timer, a SysTick exception is
 * generated when the SysTick timer reaches zero. Software can also
 * generate a SysTick exception. In an OS environment, the processor can
 * use this exception as system tick.
 */
void __attribute__((interrupt)) sys_tick_handler(void) {}

/** System IRQ handler */
void __attribute__((interrupt)) system_handler(void) {}

/** WDT IRQ handler */
void __attribute__((interrupt)) wdt_handler(void) {}

/** RTC IRQ handler */
void __attribute__((interrupt)) rtc_handler(void) {}

/** EIC IRQ handler */
void __attribute__((interrupt)) eic_handler(void) {}

/** FREQM IRQ handler */
void __attribute__((interrupt)) freqm_handler(void) {}

/** TSENS IRQ handler */
void __attribute__((interrupt)) tsens_handler(void) {}

/** NVMCTRL IRQ handler */
void __attribute__((interrupt)) nvmctrl_handler(void) {}

/** DMAC IRQ handler */
void __attribute__((interrupt)) dmac_handler(void) {}

/** EVSYS IRQ handler */
void __attribute__((interrupt)) evsys_handler(void) {}

/** SERCOM0 IRQ handler */
void __attribute__((interrupt)) sercom0_handler(void) {}

/** SERCOM1 IRQ handler */
void __attribute__((interrupt)) sercom1_handler(void) {}

/** SERCOM2 IRQ handler */
void __attribute__((interrupt)) sercom2_handler(void) {}

/** SERCOM3 IRQ handler */
void __attribute__((interrupt)) sercom3_handler(void) {}

/** CAN0 IRQ handler */
void __attribute__((interrupt)) can0_handler(void) {}

/** TCC0 IRQ handler */
void __attribute__((interrupt)) tcc0_handler(void) {}

/** TCC1 IRQ handler */
void __attribute__((interrupt)) tcc1_handler(void) {}

/** TCC2 IRQ handler */
void __attribute__((interrupt)) tcc2_handler(void) {}

/** TC0 IRQ handler */
void __attribute__((interrupt)) tc0_handler(void) {}

/** TC1 IRQ handler */
void __attribute__((interrupt)) tc1_handler(void) {}

/** TC2 IRQ handler */
void __attribute__((interrupt)) tc2_handler(void) {}

/** TC3 IRQ handler */
void __attribute__((interrupt)) tc3_handler(void) {}

/** TC4 IRQ handler */
void __attribute__((interrupt)) tc4_handler(void) {}

/** ADC0 IRQ handler */
void __attribute__((interrupt)) adc0_handler(void) {}

/** ADC1 IRQ handler */
void __attribute__((interrupt)) adc1_handler(void) {}

/** AC IRQ handler */
void __attribute__((interrupt)) ac_handler(void) {}

/** DAC IRQ handler */
void __attribute__((interrupt)) dac_handler(void) {}

/** SDADC IRQ handler */
void __attribute__((interrupt)) sdadc_handler(void) {}

/** PTC IRQ handler */
void __attribute__((interrupt)) ptc_handler(void) {}

/** Processor interrupt vector table. */
__attribute__((section(".vectors")))
const struct vector_table vectors =
{
	.p_stack    = &_estack,
	.reset      = reset_handler,
	.nmi        = nmi_handler,
	.hard_fault = hard_fault_handler,
	.sv_call    = sv_call_handler,
	.pend_sv    = pend_sv_handler,
	.sys_tick   = sys_tick_handler,
	.irq =
	{
		/* IRQ  0 */ system_handler,
		/* IRQ  1 */ wdt_handler,
		/* IRQ  2 */ rtc_handler,
		/* IRQ  3 */ eic_handler,
		/* IRQ  4 */ freqm_handler,
		/* IRQ  5 */ tsens_handler,
		/* IRQ  6 */ nvmctrl_handler,
		/* IRQ  7 */ dmac_handler,
		/* IRQ  8 */ evsys_handler,
		/* IRQ  9 */ sercom0_handler,
		/* IRQ 10 */ sercom1_handler,
		/* IRQ 11 */ sercom2_handler,
		/* IRQ 12 */ sercom3_handler,
		/* IRQ 13 */ 0, /** Reserved */
		/* IRQ 14 */ 0, /** Reserved */
		/* IRQ 15 */ can0_handler,
		/* IRQ 16 */ 0, /** Reserved */
		/* IRQ 17 */ tcc0_handler,
		/* IRQ 18 */ tcc1_handler,
		/* IRQ 19 */ tcc2_handler,
		/* IRQ 20 */ tc0_handler,
		/* IRQ 21 */ tc1_handler,
		/* IRQ 22 */ tc2_handler,
		/* IRQ 23 */ tc3_handler,
		/* IRQ 24 */ tc4_handler,
		/* IRQ 25 */ adc0_handler,
		/* IRQ 26 */ adc1_handler,
		/* IRQ 27 */ ac_handler,
		/* IRQ 28 */ dac_handler,
		/* IRQ 29 */ sdadc_handler,
		/* IRQ 30 */ ptc_handler,
	},
};

const volatile struct cpuid::_cpuid* cpuid::cpuid_ro(void)
{
	return ((const volatile struct cpuid::_cpuid*) _cpuid_register_address);
}

uint8_t cpuid::get_revision(void)
{
	return cpuid_ro()->revision;
}

enum cpuid::partno cpuid::get_partno(void)
{
	return static_cast<enum cpuid::partno>(cpuid_ro()->partno);
}

enum cpuid::architecture cpuid::get_architecture(void)
{
	return static_cast<enum cpuid::architecture>(cpuid_ro()->architecture);
}

uint8_t cpuid::get_variant(void)
{
	return cpuid_ro()->variant;
}

enum cpuid::implementer cpuid::get_implementer(void)
{
	return static_cast<enum cpuid::implementer>(cpuid_ro()->implementer);
}

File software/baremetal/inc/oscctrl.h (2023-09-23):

/* SPDX-License-Identifier: MIT */
/**
 * \file      inc/oscctrl.h
 * \brief     Definitions regarding OSCCTRL registers structure
 * \copyright Copyright (c) 2023 Leon Rinkel
 */

#ifndef SAMFD_OSCCTRL_H
#define SAMFD_OSCCTRL_H

#include <stdint.h>

/** \brief OSCCTRL registers base address */
#define OSCCTRL_ADDR 0x40001000u

/** \name OSCCTRL INTENSET register */
/**@{*/

/** \brief OSCCTRL INTENSET register structure */
typedef union
{
	/** \brief Unsigned access */
	uint32_t U;
	/** \brief Bitfield access */
	struct
	{
		/** \brief XOSC ready interrupt enable */
		uint32_t XOSCRDY:1;
		/** \brief XOSC clock failure interrupt enable */
		uint32_t CLKFAIL:1;
		/** \brief Reserved */
		uint32_t :2;
		/** \brief OSC48M ready interrupt enable */
		uint32_t OSC48MRDY:1;
		/** \brief Reserved */
		uint32_t :3;
		/** \brief DPLL lock rise interrupt enable */
		uint32_t DPLLLCKR:1;
		/** \brief DPLL lock fall interrupt enable */
		uint32_t DPLLLCKF:1;
		/** \brief DPLL lock timeout interrupt enable */
		uint32_t DPLLLTO:1;
		/** \brief DPLL loop divider ratio update complete interrupt enable */
		uint32_t DPLLLDRTO:1;
		/** \brief Reserved */
		uint32_t :4;
		/** \brief Reserved */
		uint32_t :16;
	} B;
} oscctrl_intenset_t;

/** \brief OSCCTRL INTENSET register address offset */
#define OSCCTRL_INTENSET_OFF 0x04u

/** \brief OSCCTRL INTENSET register address */
#define OSCCTRL_INTENSET_ADDR (OSCCTRL_ADDR + OSCCTRL_INTENSET_OFF)

/** \brief OSCCTRL INTENSET register */
#define OSCCTRL_INTENSET (*((volatile oscctrl_intenset_t*) OSCCTRL_INTENSET_ADDR))

/** \brief OSCCTRL INTENSET.XOSCRDY bit offset */
#define OSCCTRL_INTENSET_XOSCRDY_OFF 0u
/** \brief OSCCTRL INTENSET.XOSCRDY bit mask */
#define OSCCTRL_INTENSET_XOSCRDY_MSK (0x1u << OSCCTRL_INTENSET_XOSCRDY_OFF)

/** \brief OSCCTRL INTENSET.CLKFAIL bit offset */
#define OSCCTRL_INTENSET_CLKFAIL_OFF 1u
/** \brief OSCCTRL INTENSET.CLKFAIL bit mask */
#define OSCCTRL_INTENSET_CLKFAIL_MSK (0x1u << OSCCTRL_INTENSET_CLKFAIL_OFF)

/** \brief OSCCTRL INTENSET.OSC48MRDY bit offset */
#define OSCCTRL_INTENSET_OSC48MRDY_OFF 4u
/** \brief OSCCTRL INTENSET.OSC48MRDY bit mask */
#define OSCCTRL_INTENSET_OSC48MRDY_MSK (0x1u << OSCCTRL_INTENSET_OSC48MRDY_OFF)

/** \brief OSCCTRL INTENSET.DPLLLCKR bit offset */
#define OSCCTRL_INTENSET_DPLLLCKR_OFF 8
/** \brief OSCCTRL INTENSET.DPLLLCKR bit mask */
#define OSCCTRL_INTENSET_DPLLLCKR_MSK (0x1u << OSCCTRL_INTENSET_DPLLLCKR_OFF)

/** \brief OSCCTRL INTENSET.DPLLLCKF bit offset */
#define OSCCTRL_INTENSET_DPLLLCKF_OFF 9u
/** \brief OSCCTRL INTENSET.DPLLLCKF bit mask */
#define OSCCTRL_INTENSET_DPLLLCKF_MSK (0x1u << OSCCTRL_INTENSET_DPLLLCKF_OFF)

/** \brief OSCCTRL INTENSET.DPLLLTO bit offset */
#define OSCCTRL_INTENSET_DPLLLTO_OFF 10u
/** \brief OSCCTRL INTENSET.DPLLLTO bit mask */
#define OSCCTRL_INTENSET_DPLLLTO_MSK (0x1u << OSCCTRL_INTENSET_DPLLLTO_OFF)

/** \brief OSCCTRL INTENSET.DPLLLDRTO bit offset */
#define OSCCTRL_INTENSET_DPLLLDRTO_OFF 11u
/** \brief OSCCTRL INTENSET.DPLLLDRTO bit mask */
#define OSCCTRL_INTENSET_DPLLLDRTO_MSK (0x1u << OSCCTRL_INTENSET_DPLLLDRTO_OFF)

/**@}*/

/** \name OSCCTRL INTFLAG register */
/**@{*/

/** \brief OSCCTRL INTFLAG register structure */
typedef union
{
	/** \brief Unsigned access */
	uint32_t U;
	/** \brief Bitfield access */
	struct
	{
		/** \brief XOSC ready */
		uint32_t XOSCRDY:1;
		/** \brief XOSC failure detection */
		uint32_t CLKFAIL:1;
		/** \brief Reserved */
		uint32_t :2;
		/** \brief OSC48M ready */
		uint32_t OSC48MRDY:1;
		/** \brief Reserved */
		uint32_t :3;
		/** \brief DPLL lock rise */
		uint32_t DPLLLCKR:1;
		/** \brief DPLL lock fall */
		uint32_t DPLLLCKF:1;
		/** \brief DPLL lock timeout */
		uint32_t DPLLLTO:1;
		/** \brief DPLL loop divider ratio update complete */
		uint32_t DPLLLDRTO:1;
		/** \brief Reserved */
		uint32_t :4;
		/** \brief Reserved */
		uint32_t :16;
	} B;
} oscctrl_intflag_t;

/** \brief OSCCTRL INTFLAG register address offset */
#define OSCCTRL_INTFLAG_OFF 0x08u

/** \brief OSCCTRL INTFLAG register address */
#define OSCCTRL_INTFLAG_ADDR (OSCCTRL_ADDR + OSCCTRL_INTFLAG_OFF)

/** \brief OSCCTRL INTFLAG register */
#define OSCCTRL_INTFLAG (*((volatile oscctrl_intflag_t*) OSCCTRL_INTFLAG_ADDR))

/**@}*/

/** \name OSCCTRL STATUS register */
/**@{*/

/** \brief OSCCTRL STATUS register structure */
typedef union
{
	/** \brief Unsigned access */
	uint32_t U;
	/** \brief Bitfield access */
	struct
	{
		/** \brief XOSC ready */
		uint32_t XOSCRDY:1;
		/** \brief XOSC clock failure */
		uint32_t CLKFAIL:1;
		/** \brief XOSC clock switch */
		uint32_t CLKSW:1;
		/** \brief Reserved */
		uint32_t :1;
		/** \brief OSC48M ready */
		uint32_t OSC48MRDY:1;
		/** \brief Reserved */
		uint32_t :3;
		/** \brief DPLL lock rise */
		uint32_t DPLLLCKR:1;
		/** \brief DPLL lock fall */
		uint32_t DPLLLCKF:1;
		/** \brief DPLL lock timeout */
		uint32_t DPLLLTO:1;
		/** \brief DPLL loop divider ratio update complete */
		uint32_t DPLLLDRTO:1;
		/** \brief Reserved */
		uint32_t :4;
		/** \brief Reserved */
		uint32_t :16;
	} B;
} oscctrl_status_t;

/** \brief OSCCTRL STATUS register address offset */
#define OSCCTRL_STATUS_OFF 0x0Cu

/** \brief OSCCTRL STATUS register address */
#define OSCCTRL_STATUS_ADDR (OSCCTRL_ADDR + OSCCTRL_STATUS_OFF)

/** \brief OSCCTRL STATUS register */
#define OSCCTRL_STATUS (*((volatile oscctrl_status_t*) OSCCTRL_STATUS_ADDR))

/** \brief OSCCTRL STATUS.XOSCRDY bit offset */
#define OSCCTRL_STATUS_XOSCRDY_OFF 0u
/** \brief OSCCTRL STATUS.XOSCRDY bit mask */
#define OSCCTRL_STATUS_XOSCRDY_MSK (0x1u << OSCCTRL_STATUS_XOSCRDY_OFF)

/** \brief OSCCTRL STATUS.CLKFAIL bit offset */
#define OSCCTRL_STATUS_CLKFAIL_OFF 1u
/** \brief OSCCTRL STATUS.CLKFAIL bit mask */
#define OSCCTRL_STATUS_CLKFAIL_MSK (0x1u << OSCCTRL_STATUS_CLKFAIL_OFF)

/** \brief OSCCTRL STATUS.CLKSW bit offset */
#define OSCCTRL_STATUS_CLKSW_OFF 2u
/** \brief OSCCTRL STATUS.CLKSW bit mask */
#define OSCCTRL_STATUS_CLKSW_MSK (0x1u << OSCCTRL_STATUS_CLKSW_OFF)

/** \brief OSCCTRL STATUS.OSC48MRDY bit offset */
#define OSCCTRL_STATUS_OSC48MRDY_OFF 4u
/** \brief OSCCTRL STATUS.OSC48MRDY bit mask */
#define OSCCTRL_STATUS_OSC48MRDY_MSK (0x1u << OSCCTRL_STATUS_OSC48MRDY_OFF)

/** \brief OSCCTRL STATUS.DPLLLCKR bit offset */
#define OSCCTRL_STATUS_DPLLLCKR_OFF 8u
/** \brief OSCCTRL STATUS.DPLLLCKR bit mask */
#define OSCCTRL_STATUS_DPLLLCKR_MSK (0x1u << OSCCTRL_STATUS_DPLLLCKR_OFF)

/** \brief OSCCTRL STATUS.DPLLLCKF bit offset */
#define OSCCTRL_STATUS_DPLLLCKF_OFF 9u
/** \brief OSCCTRL STATUS.DPLLLCKF bit mask */
#define OSCCTRL_STATUS_DPLLLCKF_MSK (0x1u << OSCCTRL_STATUS_DPLLLCKF_OFF)

/** \brief OSCCTRL STATUS.DPLLLTO bit offset */
#define OSCCTRL_STATUS_DPLLLTO_OFF 10u
/** \brief OSCCTRL STATUS.DPLLLTO bit mask */
#define OSCCTRL_STATUS_DPLLLTO_MSK (0x1u << OSCCTRL_STATUS_DPLLLTO_OFF)
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

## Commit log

2023-01-15 add mcu & usb schematic
    [mcu.kicad_sch, sam-fd.kicad_pcb, sam-fd.kicad_sch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]
2023-01-19 move inside hardware dir
    [mcu.kicad_sch, sam-fd.kicad_pcb, sam-fd.kicad_sch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]
2023-01-19 add can 500kbits demo code
    [flash.cfg]
2023-01-19 add can transceiver
    [can.kicad_sch, sam-fd.kicad_sch]
2023-01-23 worked on it
    [can.kicad_sch, mcu.kicad_sch, sam-fd.kicad_sch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]
2023-01-24 picked parts
    [mcu.kicad_sch, sam-fd.csv, sam-fd.kicad_sch]
2023-01-26 did a little routing
    [sam-fd.kicad_pcb, sam-fd.kicad_sch, usb.kicad_sch]
2023-01-27 ordered, pray this works
    [can.kicad_sch, mcu.kicad_sch, sam-fd-rounded.kicad_pcb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]
2023-02-11 yay this seems to work
    [flash.cfg]
2023-02-11 leds through transistor, castellated holes
    [can.kicad_sch, mcu.kicad_sch, sam-fd-rounded.kicad_pcb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]
2023-02-25 leds now active high
2023-04-08 move application to subfolder
    [flash.cfg]
2023-04-08 add serial bootloader
    [flash.cfg]
2023-04-08 build bootloader with cmake
    [flash.cfg]
2023-09-20 Add flash driver for application
2023-09-21 Baremetal blinky and uart
2023-09-22 Try out interrupts
2023-09-23 Clock failure detection is so cool
    [oscctrl.h]
2023-09-23 Add 1ms SysTick interrupt
2023-09-23 Remove arbitrary delay from UART transmission
2023-09-23 Async UART with ring buffer
2023-09-24 Add baremetal CAN driver
2023-09-24 Add UART read
2023-09-24 Add initial flash driver
2023-10-01 UART read/write functions
2023-10-12 Add basic rev2 schematic
    [can.kicad_sch, mcu.kicad_sch, sam-fd-rounded.kicad_pcb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]
